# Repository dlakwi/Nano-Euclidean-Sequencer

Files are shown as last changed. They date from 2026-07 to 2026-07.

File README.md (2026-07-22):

# Nano-Euclidean-Sequencer
Build of KeLaiFu's Nano-Euclidean-Sequencer.
Illuminated pushbuttons and toggle switch are different.

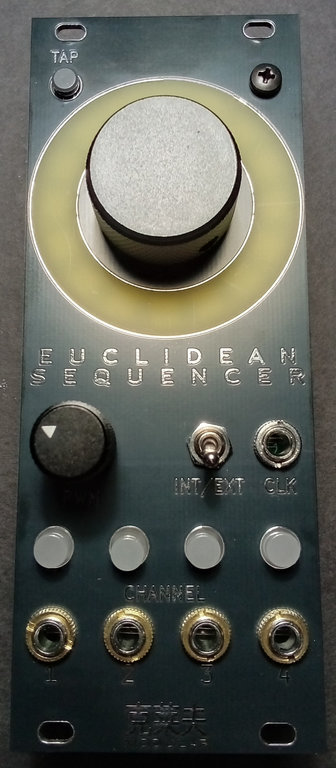
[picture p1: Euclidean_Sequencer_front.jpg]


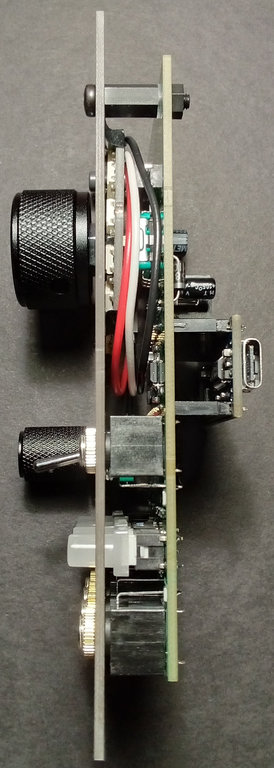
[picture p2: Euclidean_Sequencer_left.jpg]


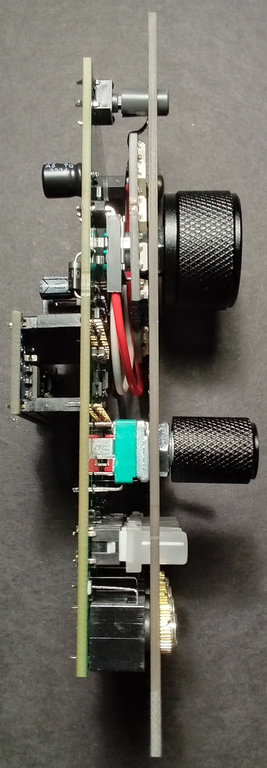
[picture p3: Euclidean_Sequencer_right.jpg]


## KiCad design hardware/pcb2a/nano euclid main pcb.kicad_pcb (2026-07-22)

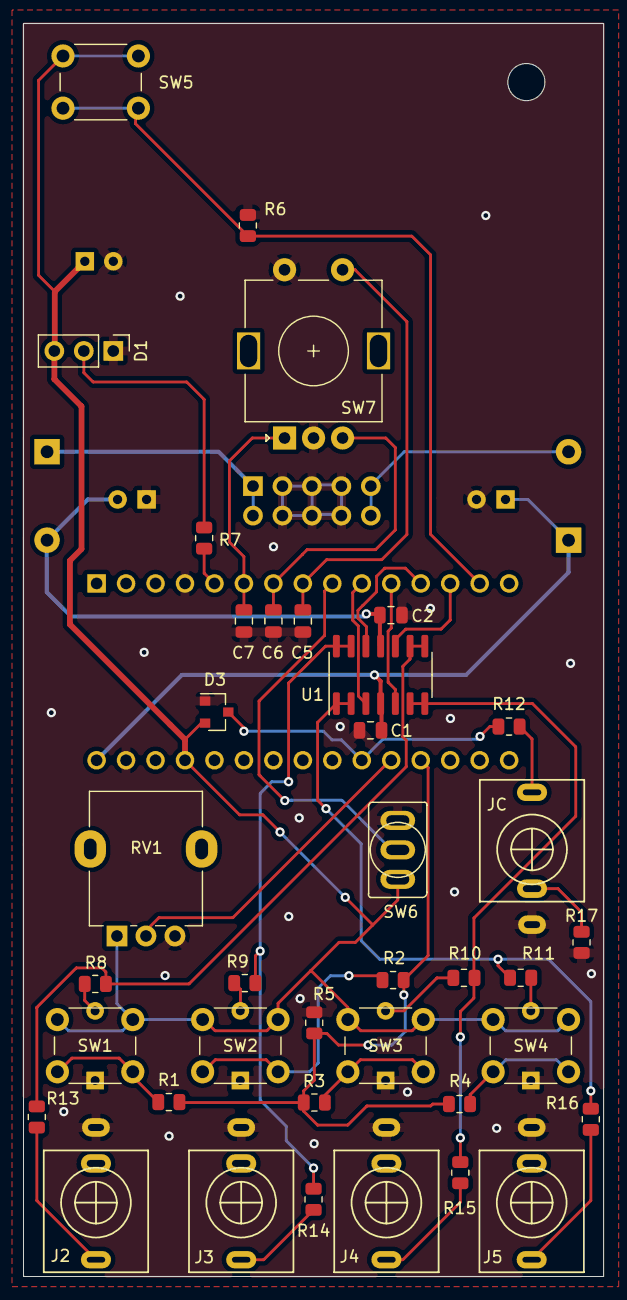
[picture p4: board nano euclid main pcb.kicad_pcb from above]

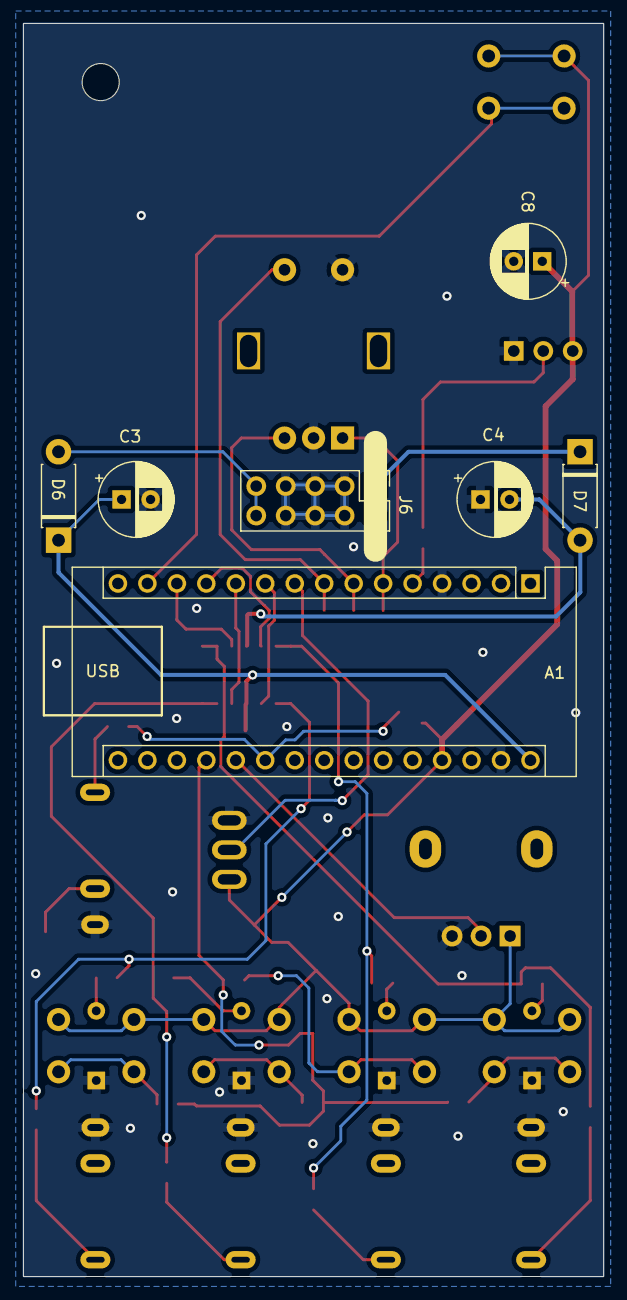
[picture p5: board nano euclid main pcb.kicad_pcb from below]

Board: 2 copper layers, 50.0 x 108.0 mm, 45 parts (7 on the bottom side), 38 nets.

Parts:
A1: Arduino_Nano_v3.x; Arduino_Nano
C1, C2: 100n; C_0805_2012Metric
C3, C4: 10u; CP_Radial_D6.3mm_P2.50mm
C5, C6, C7: 10n; C_0805_2012Metric
C8: 47u; CP_Radial_D6.3mm_P2.50mm
D1: NeoPixel_THT; PinHeader_1x03_P2.54mm_Vertical
D3: BAT54S; SOT-23
D6, D7: 1N5817; D_DO-41_SOD81_P7.62mm_Horizontal
J2, J3, J4, J5: AudioJack2_Ground; PJ398SM
J6: Synth_power_2x5; PinHeader_2x05_P2.54mm_Vertical
JC: CLOCK; PJ398SM
R1, R12, R13, R14, R15, R16: 1k; R_0805_2012Metric
R2: 2k2; R_0805_2012Metric
R3, R6, R17: 4k7; R_0805_2012Metric
R4, R5: 10k; R_0805_2012Metric
R7: 220R; R_0805_2012Metric
R8, R9, R10, R11: Rled; R_0805_2012Metric
RV1: R_Potentiometer; Potentiometer_Alpha_RD901F-40-00D_Single_Vertical
SW1, SW2, SW3, SW4: SW_Push; SW_PUSH_LED_6mm
SW5: SW_Push; SW_PUSH_6mm
SW6: Toggle_SPDT_SubMini_2pos; Switch_Toggle_SPDT_SubMini
SW7: RotaryEncoder_Switch; RotaryEncoder_Alps_EC11E-Switch_Vertical_H20mm
U1: TL074; SOIC-14_3.9x8.7mm_P1.27mm

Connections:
+12V: A1.30 (VIN), C1.1, C3.1, D6.1 (K), U1.4 (V+)
-12V: C2.1, C4.2, D7.2 (A), U1.11 (V-)
Ch1-out: R8.1, R13.2, U1.8, U1.9 (-)
Ch2-out: R9.2, R14.2, U1.13 (-), U1.14
Ch3-out: R10.2, R15.2, U1.6 (-), U1.7
Ch4-out: R11.2, R16.2, U1.1, U1.2 (-)
GND: A1.4 (GND), A1.29 (GND), C1.2, C2.2, C3.2, C4.1, C5.2, C6.2, C7.2, C8.2, D1.1 (DOUT), D3.1, J2.S, J3.S, J4.S, J5.S, J6.3 (GND), J6.4 (GND), J6.5 (GND), J6.6 (GND), J6.7 (GND), J6.8 (GND), JC.S, R5.2, R6.1, R17.1, RV1.3, SW1.4 (K), SW2.4 (K), SW3.4 (K), SW4.4 (K), SW6.1, SW7.C, SW7.S2
JC-TN: JC.TN, R17.2
unnamed: A1.5 (D2), R7.2
unnamed: A1.6 (D3), C7.1, SW7.A
unnamed: A1.7 (D4), C6.1, SW7.B
unnamed: A1.8 (D5), C5.1, SW7.S1
unnamed: A1.9 (D6), SW6.2
unnamed: A1.10 (D7), U1.3 (+)
unnamed: A1.11 (D8), U1.5 (+)
unnamed: A1.12 (D9), U1.12 (+)
unnamed: A1.13 (D10), U1.10 (+)
unnamed: A1.14 (D11), R6.2, SW5.2
unnamed: A1.19 (A0), R1.1, R2.1, R3.1, R4.1, R5.1
unnamed: A1.20 (A1), RV1.2
unnamed: A1.21 (A2), D3.3, R12.2
unnamed: A1.27 (+5V), C8.1, D1.3 (VDD), D3.2, RV1.1, SW1.1, SW2.1, SW3.1, SW4.1, SW5.1, SW6.3
unnamed: D1.2 (GND), R7.1
unnamed: D6.2 (A), J6.9 (+12V), J6.10 (+12V)
unnamed: D7.1 (K), J6.1 (-12V), J6.2 (-12V)
unnamed: J2.T, R13.1
unnamed: J3.T, R14.1
unnamed: J4.T, R15.1
unnamed: J5.T, R16.1
unnamed: JC.T, R12.1
unnamed: R1.2, SW1.2
unnamed: R2.2, SW2.2
unnamed: R3.2, SW3.2
unnamed: R4.2, SW4.2
unnamed: R8.2, SW1.3 (A)
unnamed: R10.1, SW3.3 (A)
unnamed: R11.1, SW4.3 (A)
unnamed: R9.1, SW2.3 (A)

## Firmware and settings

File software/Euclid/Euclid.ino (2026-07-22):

/*
 *   Program:      Euclidean Rhythm Generator Kosmo/Eurorack
 *   Author:       L J Brackney,
 *   Organization: Suncoast Polytechnical High School
 *   Version:      1.0
 *   Date:         11/21/2021
 *
 *   Adapted by Jos Bouten, Jan ... Apr 2022
 *   Added support for shift button, clock out, 4 function inputs
 *   - Added variable pattern length
 *   - To change the tempo the shift/tap tempo button needs to be pressed while the rotary encoder is rotated.
 *   - Changed all channel dependent variables into arrays.
 *   - Used capitals for constants, camel case for variables and function calls
 *   - Setting the speed depends on pressing the tap tempo button.
 *   - While setting the speed, the pattern leds show a white background pattern.
 *   - Added storing, recalling and clearing of patches in EEPROM.
 *   - The channel chosen last will be recalled on startup.
 * 
 * 2022-04-27: Whenever you change the pattern length, or change the number of Euclidean Rhythm pulses,
 *             a new euclidean pattern is generated and this pattern is started from its starting position for the active pattern.
 * 2022-04-29: The mode from which a jump into program mode is made is restored when leaving program mode.
 * 2022-05-05: Code adapted to function inputs using negative logic.
 *
 *  Compile, upload and run the code one time with the INITIALIZE flag set.
 *  This will result in the nano writing 16 patches to its EEPROM.
 *  One patch will contain a pattern, the others are empty patches.
 *  Next comment out the line "#define INITIALIZE 1" and compile, upload and run the code.
 *  This will program the Euclidean sequencer code into the nano which will be run each time you start up the nano.
 *  The nano will read the patches from memory each time it starts and chooses the patch you saved last.
 *
 *  Upon startup the sequencer is in 'Pattern Length / Tempo Mode'.
 *  When pressing the rotary encoder you can switch to the second mode, 'Num Pulse Mode'.
 *  Press it again and the mode is 'Rotate Mode'.
 *  Press again and the mode returns to 'Pattern Length / Tempo Mode'.
 *
 *  In 'Pattern Mode' rotating the encoder will increase or decrease the pattern length of the chosen trigger channel.
 *  Each time you change the length of the pattern a new fitting Euclidean pattern is generated depending on the number of pulses chosen (see below) for this pattern.
 *  Rotating the dial with the tap tempo / shift button pressed at the same time, will allow for changing tempo of the sequencer's internal clock.
 *  In 'Num Pulse Mode' the encoder can be used to set the number of trigger pulses for the chosen trigger channel.
 *  The pulses will follow a Euclidean pattern.
 *  In 'Rotate Mode' it is possible to shift the trigger pulse pattern accross the total length of the pattern.
 *
 *  Pressing the shift button and the rotary switch at the same time will select the 'Program Mode'.
 *  Using the rotary encoder's knob 1 of 16 memory cells can be selected.
 *  Pressing the trigger channel D button will store the current pattern of the selected trigger channel to the corresponding memory cell.
 *  Pressing the trigger channel A button will recall the patch pattern stored in the EEPROM memory cell and store it in
 *    the sequencer's active memory at the patch number selected with the rotary dial.
 *  Pressing the trigger channel B button will clear the patch in the eeprom the rotary encoder is set to.
 *  The pattern already in the working memory however will not be changed. Don't forget to save it is you like it.
 *
 *  The LEDs will light up red for the locations containing a patch and green for the locations that are cleared.
 *  When in 'Program Mode' pressing the rotary switch will switch to 'Pattern Length / Tempo Mode'.
 *
 * 2022-02-27: some changes to hardware and software
 *  - deactivated pattern length change menu because this is hardly ever used and is a nuisance to have to click through.
 *  - added tempo change to rotate and pulse number menu.
 *  - adapted ext clock in and func in to positive logic after hardware change.
 *  - changed the range of the pulse width knob so that the output pulses range from about 10% to 99% of the clock cyle time.
 *  - changed the duty cycle of the clock out to be fixed at 50%.
 *
 * 2026-07-19: software changes -- dlakwi Ensign / donald johnson
 *  - reactivated pattern length change
 *  - added encoder 'accelaration' to internal tempo change for setting tempo quicker
 *  - changed length colour to cyan since channel 4 colour is yellow
 *  - added NeoPixel brightness set
 *  - removed code for Euclid-O-Matic hardware
 */

#include <Adafruit_NeoPixel.h>    // Include Adafruit_NeoPixel library
#include <Encoder.h>              // Include rotary encoder library
#include <EEPROM.h>

// Run program once using INITIALIZE to set some initial values in the EEPROM
//#define INITIALIZE 1

// pins

#define PIXEL_PIN             2  // Attach NeoPixel ring to digital pin 2
#define PROG_PIN              5  // Attach rotary encoder switch to digital pin 5
#define CLOCK_SOURCE_PIN      6  // Attach external clock select switch to digital pin 6
#define TRIG_A_PIN           10  //   swap pins 7 and 10 than to resolder things. :)
#define TRIG_B_PIN            9  //   assembling the modules, and it was easier to
#define TRIG_C_PIN            8  //   digital pins 7-10.  I mixed up two wires when
#define TRIG_D_PIN            7  // Attach the four drum/voice trigger output pins to 
#define BUTTON_PIN           A0  // The trigger select buttons are on a voltage divider attached to A0
#define PWM_POT_PIN          A1  // The pulse width potentiometer is attached to analog pin A1
#define EXT_CLOCK_IN_PIN     A2  // Ext Clock in
#define ENC_A_PIN             3
#define ENC_B_PIN             4

#define SHIFT_PIN            11  // Shift Function button on D11 
#define ON  LOW
#define OFF HIGH

// defines

// Show some debug info on the serial port.
//#define DEBUG 1

#define NUM_CHANNELS           4

// array indexes step[], pulses[], patternLength[], channelPattern[]  --  not 0 1 2 3
#define CH_A_1                 3  // Pattern/trigger A/1 == red
#define CH_B_2                 2  // Pattern/trigger B/2 == green
#define CH_C_3                 1  // Pattern/trigger C/3 == blue
#define CH_D_4                 0  // Pattern/trigger D/4 == yellow

char CHANNEL_NAMES[NUM_CHANNELS] = { 'D', 'C', 'B', 'A' };

// Modes you can choose by pressing the rotary encoder's button.
#define PATTERN_LENGTH_MODE    1  // also used as "pulse length mode"
#define NUM_PULSE_MODE         2
#define ROTATE_MODE            3
#define PROGRAM_MODE           4  // Allows to store patterns in EEPROM or to recall them.
                                  // This mode can only be reached by pressing the shift button AND the rotary encoder button.
#define MAX_MODE               3  // Note, we do not count PROGRAM_MODE here.

// Activate this if you allow pattern length change
#define ALLOW_PATTERN_LENGTH_CHANGE 1

#define MIN_DELAY_TIME        10  // Limit the fastest loop time to 10 mS per step -- Change if you want faster tempos.
#define MAX_DELAY_TIME      2000  // Limit the slowest loop time to 1 sec per step -- Change if you want slower tempos.
#define INIT_DELAY_TIME      500

#define MAX_ADC_VALUE       1000  // This number was determined empirically.
#define HALF_DAC_RANGE       500

#define BRIGHTNESS           192
#define NUM_NEOP_LEDS         16  // The number of LEDs in the neopixel wheel.
#define NR_OF_MEMORY_CELLS     NUM_NEOP_LEDS
// Use the switches below to make the brightness of the neopixel oscillate.
  #define LED_FX               1  // Oscillate LEDs in all modes except PROGRAM_MODE.
//#define LED_FX_BLACK         1  // When set the intensity will fall back to 0, otherwise to 1.
  #define PATCH_MEMORY_LED_FX  1  // Also oscillate LED intensity in PROGRAM_MODE

#define EEPROM_BASE_ADDRESS    0

#define CHECK_BIT(var, pos) ((var) & (1 << (pos)))

#ifdef DEBUG
char msg[255];
#endif

// ----------------

static int        step          [NUM_CHANNELS];  // The active step for each trigger channel.

struct            Patch
{
  int             pulses        [NUM_CHANNELS];  // The number of pulses to be generated for each of the triggers.
  int             patternLength [NUM_CHANNELS];  // The pattern length for each trigger output.
  unsigned int    channelPattern[NUM_CHANNELS];  // The pattern of Euclidean distributed pulses,
};

Patch             emptyPatch;
Patch             currentPatch;       // The patch the sequencer is playing.

Patch             patches[NR_OF_MEMORY_CELLS];
int               chosenPatchNumber      = 0;
int               candidatePatchNumber   = 0;
int               selectedTriggerChannel = -1;

int               delayTime              = INIT_DELAY_TIME;  // The time between steps persists in each loop.
unsigned int      memoryCellsInUse       = 0;


Encoder           myEnc( ENC_A_PIN, ENC_B_PIN );  // Attach rotary encoder - swap if encoder is 'backwards'

Adafruit_NeoPixel pixels( NUM_NEOP_LEDS, PIXEL_PIN, NEO_GRB + NEO_KHZ800 );  // Set up the NeoPixel ring

// ----------------

void setup( void )
{
#ifdef DEBUG
  // Set up the serial console for debugging messages
  Serial.begin( 115200 );
#endif

#ifdef INITIALIZE
  initializePatchInEeprom();
  pinMode( 13, OUTPUT );  // Nano LED
  digitalWrite( 13, 0 );
#ifdef DEBUG
  Serial.println( "Successfuly written 16 default patches to EEPROM." );
#endif

#else
  pinMode( PROG_PIN,          INPUT_PULLUP );  // Assign the encoder switch which closes to ground and uses an internal pullup resistor.
  pinMode( CLOCK_SOURCE_PIN,  INPUT );         // Assign the external clock selector switch.
  pinMode( TRIG_D_PIN,        OUTPUT );        // Assign trigger 1 out.
  pinMode( TRIG_C_PIN,        OUTPUT );        // Assign trigger 2 out.
  pinMode( TRIG_B_PIN,        OUTPUT );        // Assign trigger 3 out.
  pinMode( TRIG_A_PIN,        OUTPUT );        // Assign trigger 4 out.
  pinMode( EXT_CLOCK_IN_PIN,  INPUT );         // Assign external clock input.
  pinMode( SHIFT_PIN,         INPUT );         // Assign "tap"/shift button.

  pixels.begin();                              // Start the NeoPixel
  pixels.setBrightness( BRIGHTNESS );
  pixels.clear();

  testLedsAndPixels();                         // Show that leds and pixels are working.

  // Read all 16 stored (empty or not) patches from EEPROM.
  chosenPatchNumber    = readPatchesFromEEPROM( patches, memoryCellsInUse, delayTime, selectedTriggerChannel );
  candidatePatchNumber = chosenPatchNumber;

  // Load the current patch with the stored information.
  copyPatch( patches[chosenPatchNumber], currentPatch );

#ifdef DEBUG
  sprintf( msg, "Reading patch info from EEPROM." );        Serial.println( msg );
  sprintf( msg, "Restoring patch: %d", chosenPatchNumber ); Serial.println( msg );
  displayPatch( currentPatch );
  sprintf( msg, "Setting speed to: %d", delayTime );                              Serial.println( msg );
  sprintf( msg, "Selecting channel: %c", CHANNEL_NAMES[selectedTriggerChannel] ); Serial.println( msg );
#endif

#endif

  // Initialize step count for each trigger channel.
  for ( int triggerChannel = 0; triggerChannel < NUM_CHANNELS; triggerChannel++ )
  {
    step[triggerChannel] = 0;
  }

  createEmptyPatch( emptyPatch );
}

#ifdef INITIALIZE

void loop( void )
{
  static byte led = 0;
#ifdef DEBUG
  Serial.println( "Now recompile and upload with #define INITIALIZE commented out" );
  Serial.println( "to run Euclid-O-Matic (a Euclidean sequencer / rhythm generator." );
#endif
  led = !led;
  digitalWrite( 13, led );  // blink LED
  delay( 1000 );
}

#else

static long oldPosition;  // Previous encoder reading.
static long newPosition;  // Current  encoder reading.

void loop( void )
{
#ifdef ALLOW_PATTERN_LENGTH_CHANGE
  static int           mode                   = PATTERN_LENGTH_MODE;
#else
  static int           mode                   = NUM_PULSE_MODE;
#endif
  static int           prevMode               = 0;
  static long          mode1Pos               = 0;                                // The last encoder position in mode 1 is stored for a future return to that mode.
  static int           prevExtClk             = 0;                                // Store the previous External Clock Pulse value for transition checking.
  static unsigned long thisTime;                                                  // Prepare to query the Nano's clock.
  static unsigned long prevTime               = 0;                                // Keep track of how much time elapses between loops.
  static bool          prevProg;                                                  // Keep track of the previous encoder switch state.
  static bool          prog;                                                      // Prepare to read the current encoder switch state.

  bool                 triggered              = false;                            // Assume that no new step is going to occur this loop.
                       newPosition            = myEnc.read();                     // Read the current number of encoder counts.
  int                  triggerWidthPotValue   = analogRead( PWM_POT_PIN );        // Read the trigger pulse width potentiometer value.
  bool                 extClk                 = digitalRead( CLOCK_SOURCE_PIN );  //
  int                  extClkV                = analogRead( EXT_CLOCK_IN_PIN );   // Read the external clock input.
  int                  shiftButton            = digitalRead( SHIFT_PIN );         // Read the shift button (will be HIGH when pressed);

  int                  programButtonName      = -1;
  int                  programButtonValue;
  static int           prevProgramButtonValue = 0;
  boolean              change                 = false;
  int                  R = 0, G = 0, B = 0;

  if ( mode == PROGRAM_MODE )
  {
    programButtonValue = checkProgramButtons( programButtonName );         // Find out whether Trig A, B or D was pressed.
    if ( programButtonValue == 0 )                                         // No button was pressed.
    {
      prevProgramButtonValue = 0;
    }
  }
  else
  {
    change = checkButtons( selectedTriggerChannel, shiftButton );          // Query the trigger buttons and update the active trigger if needed.
    if ( change )                                                          // Remember the channel chosen (this will be recalled when powering up).
    {
      writeTriggerChannelToEEPROM( selectedTriggerChannel );
    }
  }

  prevProg = prog;                                                         // Store the last encoder switch position.
  prog     = digitalRead( PROG_PIN );                                      // Get the current encoder switch position.

  thisTime = millis();                                                     // Get the current Nano clock value in msec.

  if ( ( prog == true ) && ( prevProg == false ) )                         // If the encoder switch was just pressed, we need to switch modes.
  {
    if ( mode == 1 ) mode1Pos = newPosition;                               // Store the current encoder position for a future return to that mode.

    if ( shiftButton )                                                     // If the shift button is pressed as well, then we start the program mode.
    {
      prevMode = mode;
      mode     = PROGRAM_MODE;
    }
    else
    {
      if ( mode == PROGRAM_MODE )
      {
        mode = prevMode;                                                   // Return to mode from which we jumped into program mode
      }
      else
      {
        mode++;                                                            // Cycle to the next mode.
        if ( mode > MAX_MODE )
#ifdef ALLOW_PATTERN_LENGTH_CHANGE
          mode = PATTERN_LENGTH_MODE;
#else
          mode = NUM_PULSE_MODE;
#endif
        if ( mode == PATTERN_LENGTH_MODE )                                 // Restore the encoder position when last in the current mode.
        {
          myEnc.write( mode1Pos );
          newPosition = mode1Pos;
        }
      }
    }

    oldPosition = newPosition;
  }

  ClearNeoPixelPattern();                                                  // Clear the NeoPixel ring in preparation for any changes to the pattern.

  switch ( mode )
  {
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

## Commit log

2026-07-22 Create nano euclid transl panel.kicad_pro
2026-07-22 Create nano euclid main pcb.kicad_pro
